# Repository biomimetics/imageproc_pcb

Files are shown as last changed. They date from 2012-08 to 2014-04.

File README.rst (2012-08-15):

This work is licensed under the `Creative Commons Attribution 3.0
Unported License <http://creativecommons.org/licenses/by/3.0/>`_.

================================
ImageProc printed circuit boards
================================

Description:
 ImageProc family of printed circuit boards, which use Microchip's dsPIC
 architecture.

Download boards:
 https://github.com/biomimetics/imageproc_pcb

Citing the boards:
 If you would like to reference these boards in a publication, please
 refer to the url and cite these conference papers:

 - *For ImageProc v.1.x:*

   | Fernando L. Garcia Bermudez and Ronald S. Fearing (2009)
   | `Optical Flow on a Flapping Wing Robot
     <http://dx.doi.org/10.1109/IROS.2009.5354337>`_
   | In IROS 2009. St. Louis, MO, USA.

 - *For ImageProc v.2.0-v2.4-x:*

   | Stanley S. Baek, Fernando L. Garcia Bermudez, and Ronald S. Fearing (2011)
   | `Flight Control for Target Seeking by 13 gram Ornithopter
     <http://dx.doi.org/10.1109/IROS.2011.6094581>`_
   | In IROS 2011. San Francisco, CA, USA.

 - *For ImageProc v2.5-x:*

   | Ryan C. Julian, Douglas D. Hutchings, and Ronald S. Fearing (2012)
   | This design is pending publication.

 This material is based upon work supported by the National Science
 Foundation under Grant No. IIS-0705429 and IIS-0931463. Any opinions,
 findings, and conclusions or recommendations expressed in this material
 are those of the author(s) and do not necessarily reflect the views of
 the National Science Foundation.

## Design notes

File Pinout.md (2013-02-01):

| Pin number | dsPIC ports | ImageProc port(s) | Net name | Function description |
| --- | --- | --- | --- | --- |
| 1 | PWM3H/RE5 | PWM3H/RE5 | MOTOR_C_IN1 | Motor C H-bridge input 1 |
| 2 | PWM4L/RE6 | PWM4L/RE6 | MOTOR_D_IN2 | Motor D H-bridge input 2 |
| 3 | PWM4H/RE7 | PWM4H/RE7 | MOTOR_D_IN1 | Motor D H-bridge input 1 |
| 4 | SCK2/CN8/RG6 | SCK2 | SCK2 | SPI2 for flash and MPU |
| 5 | SDI2/CN9/RG7 | SDI2 | SDI2 | SPI2 for flash and MPU |
| 6 | SDO2/CN10/RG8 | SDO2 | SDO2 | SPI2 for flash and MPU |
| 7 | nMCLR | nMCLR | !RESET | Reset signal (JP1.5) |
| 8 | nSS2/CN11/RG9 | nSS2 | !SS2_1 | SPI2 slave select 1 (flash) |
| 9 | VSS | VSS | GND | Ground |
| 10 | VDD | VDD | 3.3V | Power |
| 11 | AN5/QEB/IC8/CN7/RB5 | - | AN5/QEB/IC8/RB5  | Auxiliary pad 4 |
| 12 | AN4/QEA/IC7/CN6/RB4 | - | AN4/QEA/IC7/RB4  | Auxiliary pad 3 |
| 13 | AN3/INDX/CN5/RB3 | - | AN3/INDX/RB3 | Auxiliary pad 2 |
| 14 | AN2/nSS1/CN4/RB2 | nSS1 | nSS1 | SPI1 for radio |
| 15 | PGEC3/AN1/VREF-/CN3/RB1 | - | AN1/RB1 | Auxiliary pad 1 |
| 16 | PGED3/AN0/VREF+/CN2/RB0 | AN0 | BATT_LEVEL | Battery level sense |
| 17 | PGEC1/AN6/OCFA/RB6 | PGEC1 | PGC | In-circuit debugger (JP1.1) |
| 18 | PGED1/AN7/RB7 | PGED1 | PGD | In-circuit debugger (JP1.2) |
| 19 | AVDD | AVDD | 3.3V | Analog power |
| 20 | AVSS | AVSS | GND | Analog ground |
| 21 | nU2CTS/AN8/RB8 | AN8 | MOTOR_A_BEMF | Motor A BEMF sense |
| 22 | AN9/RB9 | AN9 | MOTOR_B_BEMF | Motor B BEMF sense |
| 23 | TMS/AN10/RB10 | AN10 | MOTOR_C_BEMF | Motor C BEMF sense |
| 24 | TDO/AN11/RB11 | AN11 | MOTOR_D_BEMF | Motor D BEMF sense |
| 25 | VSS | VSS | GND | Ground |
| 26 | VDD | VDD | 3.3V | Power |
| 27 | TCK/AN1/RB12 | RB12 | RD_LED | Red LED |
| 28 | TDO/AN13/RB13 | RB13 | GN_LED | Green LED |
| 29 | nU2RTS/AN14/RB14 | RB14 | YW_LED | Yellow LED |
| 30 | AN15/OCFB/CN12/RB15 | RB15 | RADIO_SLP_TR | Radio control signal |
| 31 | U2RX/SDA2/CN17/RF4 | U2RX | U2RX | Auxiliary UART Rx (JP2.6) |
| 32 | U2TX/SCL2/CN18/RF5 | U2TX | U2TX | Auxiliary UART Tx (JP2.4) |
| 33 | U1TX/SDO1/RF3 | SDO1 | SDO1 | SPI1 for radio |
| 34 | U1RX/SDI1/RF2 | SDI1 | SDI1 | SPI1 for radio |
| 35 | nU2RTS/SCK1/INT0/RF6 | SCK1 | SCK1 | SPI1 for radio |
| 36 | SDA1/RG3 | SDA1 | SDA1 | I2C1 for camera and encoders  |
| 37 | SCL1/RG2 | SCL1 | SCL1 | I2C1 for camera and encoders  |
| 38 | VDD | VDD | 3.3V | Power |
| 39 | OSC1/CLKIN/RC12 | OSC1 | 40MHZ | 40 MHz main oscillator |
| 40 | OSC2/CLKO/RC15 | RC15 | !SS2_2 | SPI2 slave select 2 (MPU) |
| 41 | VSS | VSS | GND | Ground |
| 42 | IC1/nFLTA/INT1/RD8 | INT1 | IMU_IRQ | MPU interrupt |
| 43 | IC2/nU1CTS/nFLTB/INT2/RD9 | INT2 | LOWBATT_IRQ | Low voltage detect interrupt  |
| 44 | IC3/INT3/RD10 | - | IC3/INT3/RD10 | Auxiliary pad 5 |
| 45 | IC4/INT4/RD11 | INT4 | RADIO_IRQ | Radio IRQ interrupt |
| 46 | OC1/RD0 | RD0 | CAM_D0 | Parallel camera bit 0 |
| 47 | PGED2/SOSCI/T4CK/CN1/RC13 | RC13 | CAM_VSYNC | Parallel camera vertical sync |
| 48 | PGEC2/SOSCO/T1CK/CN0/RC14 | RC14 | CAM_PWDM | Parallel camera power down |
| 49 | OC2/RD1 | RD1 | CAM_D1 | Parallel camera bit 1 |
| 50 | OC3/RD2 | RD2 | CAM_D2 | Parallel camera bit 2 |
| 51 | OC4/RD3 | RD3 | CAM_D3 | Parallel camera bit 3 |
| 52 | OC5/IC5/CN13/RD4 | RD4 | CAM_D4 | Parallel camera bit 4 |
| 53 | OC6/IC6/CN14/RD5 | RD5 | CAM_D5 | Parallel camera bit 5 |
| 54 | OC7/CN15/RD6 | RD6 | CAM_D6 | Parallel camera bit 6 |
| 55 | OC8/UPDN/CN16/RD7 | RD7 | CAM_D7 | Parallel camera bit 7 |
| 56 | VCAP | VCAP | N$28 | Charge pump capacitor | 
| 57 | VDD | VDD | 3.3V | Power |
| 58 | C1RX/RF0 | RF0 | CAM_HREF | Parallel camera horiz sync |
| 59 | C1TX/RF1 | RF1 | CAM_PCLK | Parallel camera pixel clock |
| 60 | PWM1L/RE0 | PWM1L/RE0 | MOTOR_A_IN2 | Motor A H-bridge input 2 |
| 61 | PWM1H/RE1 | PWM1H/RE1 | MOTOR_A_IN1 | Motor A H-bridge input 1 |
| 62 | PWM2L/RE2 | PWM2L/RE2 | MOTOR_B_IN2 | Motor B H-bridge input 2 |
| 63 | PWM2H/RE3 | PWM2H/RE3 | MOTOR_B_IN1 | Motor B H-bridge input 1 |
| 64 | PWM3L/RE4 | PWM3L/RE4 | MOTOR_C_IN2 | Motor C H-bridge input 2 |

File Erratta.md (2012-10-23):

ImageProc 2.5 Errata

=Revision C=

=Revision B=
* SCL1 and SDA1 are transposed on the dsPIC33 footprint

=Revision A=

*V_batt plane connecting to the vregs.

Symptom:
The voltage regulators do not draw power from the battery

Reason:
The V_batt source does not connect to the portion of the V_batt plane that the voltage regulators draw power from. This occurs because the V_batt plane was cut off due to the vias that power IC7. This connection is made in Eagle, but the gerbers that the manufactuer uses exlucded the connection.

Short term resolution: Airwire between one of the three isolated vias (one each for the two vregs, one for the top H-bridge chip), and a portion of v_batt that is connected (typically, the other v_batt via for IC7).

Long Term Resoultion: Re-route those two wires that are cutting the majority of the plane off.

* Programming Connector pinouts

Symptom: The dsPIC cannot be programmed with legacy programming adaptors

Reason: The programming connector does not have the same pinouts as the programming connector on ImageProc 2.4

Short Term Resolution: Plug in the prog connector with the cable, and ensure that the cable is upside down on the connector. Then, before the final connector interfaces with the pic kit, use male-female wires to rearrange the pins to the correct orientation.

Long Term Resolution: re-do the connector on the schematic and board files.

* IC7 ground pin

Symptom: IC7, one of the two motor controllers, does not work.

Reason: One of its three ground pins, specifically, pin 11, is soldered to a pad that is in fact not connected with ground.

Short Term Resolution: Airwire between than pad and a source of ground.

Long Term Resoultion: A new route that connects ground.

* C40 and C37 mix-up

Symptom: C40, the bypass capacator for the flash mem, and C37, the bypass capacator for the IMU, have been mislabled as eachother.

Short Term resolution: Populate both C37 and C40.  Both C37 and C40 have the same value.

Long Term: Re-lable the eagle file.

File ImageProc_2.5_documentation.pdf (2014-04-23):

U_BATT

| | | | 3.3U | | 2.5U
U_BATT | U_BATT ~ | ~
~ | ~ | IC2 | IC3
U_BATT | a | ~ | 1 | ::C1 | 1 | ::C2
IC1 | VIN | VIN BATT _LEUEL
_g__ | IiuF | _g__ | IiuF C3 | ,___]__ | UIN | _____2____ L 0 W B A TT _IRQ | iuF | ,___'[ | EN_3.3l) 3.3l) | iuF | ,___'[ | EN_2.5l) 2.5l)
0.1uF: = 1 | lJOUT | C6 | c,= = | C5: = uss | ~
= =0.1uF
___2 | EN_3.0l) | 3.0 | )j_ | GND | ___2 | EN_1.8l) 1.8l) | )j_ | GND ~ N | N XC61GC3002HR-G | a | 2•2 | 2•2
GND | GND | 3.0U | GND | 1.8U
do | GND
MIC5335 SPYMT
GND

MIC5335 JGYMT

~ | ~
::C7 | ::CB
JuF | JuF
GND | GND

Biomimetic Millisldstems Labor atorld
Department of EECS., Universitld of California., Berkeleld CopldriCJht 2012 UC ReCJents" All riCJhts reserved"
TITLE: ImagePmc_2.5
Design by: | REV:
Ryan Julian (ryan julian@ berkeley. e d u) | A
Date: 7/26/12 11:03 AM | Sheet: 1/5

ICiRESET/CLOCK/DEBUG
u | RESET /CLOCK/DEBUG
il_~'v·~?~k--~DCSCT~~~~PM~CCLP~~~~~c=~~~P~G~ED~1~/~A~N~7/~R;B;7~~ PGD
R3 | i0MH2____]_.9_ OSC1/CLKIN/RC12 | PGEC1/AN6/0CFA/R86 | 1Z__ PGC
LOWBATT _IRQ | ____g RADIO_IRQ | _12
AN1/RB1 | | ~
AN3/INDX/RB3 | | ~
ANi/QEA/IC7/RBi ~
AN5/QEB/IC8/RB5 ~
RD_LED | | ~
GN_LED | | ~
YW LED | | ~
RADID_SLP_TR | | ~

DSPIC33FJ128MC706A

ICiGPIO
GPID
IC2/U1CTS/FLTB/INT2/PD8 | OC1/RDO
IC1/INT1/PDii | OC2/RD1
OC3/RD2
PGEC3/AN1/UPEF-/CN3/P81 | OC1/PD3
AN3/INDX/CN5/P83 | DC5/IC5/CN13/PD1
AN1/QEA/IC7/CN6/P81 | DC6/IC6/CN11/PD5
AN5/QE8/IC8/CN7/P85 | OC7/CN15/PD6
TCK/AN12/P812 | OC8/UPDN/CN16/PD7
TDI/AN13/R813 | 1Ci/FLTA/INT1/PD8
U2PTS/AN1 1/P811 | IC3/INT3/PD10
AN15/0CFB/CN12/P815

~ CAM_D0
~ CAM_Di
~ CAM_D2
~ CAM_D3
~ CAM_Di
~ CAM_D5
~ CAM_D6
~ CAM 07 ~ IMU -IRQ
ii_ IC3/INT3/R010

CAM_USYNC
CAM_PWDN | ~ | PGED2/SOSCI/T1CK/CN1/PC13
| ~ | PGEC2/SOSCO/T1CK/CNO/PC11
C1RX/PFO | ~ CAM_HREF
C1 TX/PFi | ~ CAM_PCLK
| | DSPIC33FJ128MC706A

3.3U
OSCi
4 UDD OUT ]_______ i0MHZ
C9 :: | _.1_ EN | GND 2

I 0·iuF ECS 2033 100

GND | GND
IC"'-P _AUDD | IC"'-P _U00@10 IC"'-P _U00@26 IC"'-P _U00@38 IC"'-P _U00@57 IC"'-P _UCAP I
r( 3.3U | 3.3U | 3.3U

# ~~11 ~f112 ~f113 3.3U

# ~hCH 1C15

:t!0.1uF | r0.1uF | :t!0.1uF | J!0.1uF | I0.1uF | Ii.7uF
| | | | GND | GND
GND | GND | GND | GND

IC"'-SERIAL
SERIAL
SCKi ~ U1PTS/SCK1/INTO/PF6 | SCK2/CN8/PG6 SOil~ U1PX/SDI1/PF2 | SDI2/CN8/PG7
SDOi ~ U1TX/SDD1/PF3 | SD02/CN10/PG8
3.3U | SSi ___l_i AN2/SS1/CN1/P82 | SS2/CN11/PG8
OSC2/CLKO/PC15
i.7k | SCI 1 | 36 | SCL1/PG2 | U2TX/SCL2/CN18/PF5
R' | | 37 | SDA1/PG3 | U2PX/SDA2/CN17/PF1
i.7k J | DSPIC33FJ128MC706A

R5

IC"'-PWM
PWM

MOTOR_A_INi ~ PWM1H/PE1
MOTOR_A_IN2 ____g_Q_ PWM1L/PEO

PWM3H/PE5
PWM3L/PE1

~ SCK2
~ SDI2
~ SD02
~ SS2 1
.iQ_ SS2=2

~ U2TX
].1_ U2RX
MOTOR_B_INi ----@- PWM2H/PE3 | PWM1H/RE7 ~ MOTOR_D_INi
MOTOR_B_IN2 _____gl_ PWM2L/PE2 | PWM1L/RE6 L_ MOTOR_D_IN2
~DS~P~I~C~3~3~F~J~12~8~M=c~7~0~6~A--------------_j

IC"'-ANALOG
ANALOG

BATT _LEUEL ___lQ PGED3/ANO/UPEF+/CN2/RBO

MOTOR_A_BEM~ ~ U2CTS/AN8/PBB MOTOR_B_BEM~ ~ AN9/PB9
MOTOR_C_BEM~ ~ TMS/AN10/P810 MOTOR_D_BEMF ____21_ TDO/ANii/PB11
| DSPIC33FJ128MC706A

Biomimetic Millisldstems Labor atorld
Department of EECS., Universitld of California., Berkeleld CopldriCJht 2012 UC ReCJents" All riCJhts reserved"
TITLE: ImagePmc_2.5
Design by:
Ryan Julian (ryan julian@ berkeley. e d u)

REV:
A
Date: 7/26/12 11:03 AM | I Sheet: 2/5

3.3U
IC5P_AUDD ~_EUDD
0.1uci ~1 121

# C20T ~~ TiuF ~_AVSS GND

IC5S
RESET | __fL_ | PST | RFP
RFN SCK1 | --+!-- | SCLK SDI1 | ~ | MISO | DIGi 5001 | ~ | MOSI | DIG2 SS1 | __2]_ | SEL
RADIO IRQ | ~ | DIG3
IRQ | DIG4- RADIO=SLP_TR ~ | SLP TP -
26 | XTALi __2L | XTAL2 | CLKM
OSC2 | AT86RF233 ZU
C18 ._:l---jOf---2- C19
10pF:~ | ;;__=::10pF

NX2520SA- 6.000000MHZ
GND | GND

3.31J
IC5P _DUDD ~ _DEIJDD
0.1ucl ~~ 123

# C22T ~~ TiuF ~_DVSS GND

4
5
+o

+- _2_

_:1Z

81
HHM171001

C16
22pF::
L;'"-

GND (") '"""
C17
22pF::

RED
LED_TX R6
.... 2.7k
GREEN
LED_RX R7
.... 2.7k

Jo
Jo

ANTi
ANT8030-2R1--01A

Biomimetic Millisldstems Labor atorld
Department of EECS., Universi1ld of California., BerkeleLJ CopLJriCJht 2012 UC ReCJents" All riCJhts reserved"
TITLE: ImagePmc_2.5
Design by: | REV:
Ryan Julian (ryanjulian@berkeley.edu) A
Date: 7/26/12 11:03 AM | I Sheet: 3/5

RB
IC7S | R9 | 15k ,7, MOTOR_A_IN1 | AIN1 | AOUTi | MOTOR_A_OUTi | MOTOR A OUTi | R29 MOTOR A IN2 | AIN2 | AOUT2 | MOTOR A OUT2 | 1 | MOTOR A BEMF
MOTOR A OUT2 | 1k | CH
R10 | LTC6088 | I2.2nF MOTOR_B_IN1 | BIN1 | BOUTi | MOTOR_B_OUTi | ,7, | IC6A
MOTOR B IN2 | BIN2 | BOUT2 | MOTOR B OUT2 | ~ | ~
~ | CD
15 | a | ~ | GND SLEEP FAULT
u BATT | u REF

A IS EN
BISEN | R12
DRU8833RTY | R13 | 15k GND | ,7, MOTOR B OUTi | R30 | MOTOR B BEMF
MOTOR B OUT2 | 1k | C'2 | 3.3U R14 | LTC6088 | I2.2nF ,7, | IC6B
CD | | ~
~ | CD a | ~ | GND | ~
u REF | "' ~ | ~
a | "' U_REF

R17
C26
R19 | 15k | ~
ICBS | ~ ,7, | "' MOTOR_C_IN1 | AIN1 | AOUTi | MOTOR_C_OUTi | MOTOR C OUTi | R31 MOTOR C IN2 | AIN2 | AOUT2 | MOTOR C OUT2 | 10 | MOTOR C BEMF
MOTOR C OUT2 | 1k | C'3
R20 | LTC6088 | I2.2nF MOTOR_D_IN1 | BIN1 | BOUTi | MOTOR_D_OUTi | ,7, | IC6C | GND
MOTOR D IN2 | BIN2 | BOUT2 | MOTOR D OUT2 | ~ | ~
N | CD
15 | a | ~ | GND SLEEP FAULT
u BATT | u REF

A IS EN
BISEN | R22
DRIJ8833RTY | R23 | 15k GND | ,7, MOTOR D OUTi | R32 16 | MOTOR D BEMF
MOTOR D OUT2 | 1k | CH
R24 | LTC6088 | I2.2nF ,7, | IC6D
CD | ~
N | CD a | ~ | GND
u REF
IC7P _IJM | IC7P _IJCP IC7P _IJINT | ICBP _IJM | ICBP _IJCP ICBP _IJINT | 3.31J
U_BATT | U_BATT | U_BATT | U_BATT | Biomimetic Millisldstems Labor atorld
~f130131 132 | ~f133131 135
IC6Ph | Department of EECS., Universitld of California., Berkeleld
T | C29 | CopldriCJht 2012 UC ReCJents" All riCJhts reserved"

p0.1uF

TITLE: ImagePmc_2.5

p22uFJ"0nF | T2uF | p22uFJ"0nF | T2uF | Design by: | REV:
Ryan Julian (ryan julian@ berkeley. e d u) | A GND
GND | GND | GND | GND | Date: 7/26/12 11:03 AM | Sheet: 4/5

U_BATT
Pi BAT+~ P2 BAT-*l

GND

YELLOW
YW_LEO | LED1
| GREEN ""
GN_LEO | LED2
RED ""

RO_LEO LED3
""
P3 | MA1 x-- MOTOR_A_OUTi
p' | MA2 x-- MOTOR A OUT2 - | -
P5 | MB1 x-- MOTOR_B_OUTi
P6 | MB2 x-- MOTOR B OUT2 - | -
P7 | MC1 x-- MOTOR_C_OUTi
PB | MC2 x-- MOTOR C OUT2 - | -
P9 | MD1 x-- MOTOR_D_OUTi
P10 MD2 x-- MOTOR D OUT2 - | -

R26

2.7k
R27

2.7k
R2B

2.7k
GND

IC9S
5CK2
5DI2 | __q_ SCL/SCLK AUX_CL + ~ ADO/SOD AUX_DA --"--
5002 | 8 | SDA/SDI
552 2 - | | cs
CAM_HREF _____11_ FSYNC | INT ______12_ IMU_IRQ

IC9P _IJOO
3.31J
~f137

~ CLKIN CLKOUT ______2_2_
A"MP"'U-,---6⁰⁰0"0"0,-----_j GND

IC9P _CPOUT IC9P _REGOUT

| 1.2nF | 1.1uF
1!0.1uF | T38 | T39
GND | GND | GND

IC10P
3.31J
~f1,0 r0.1uF

GND

3.3U

P£bfX_503 80-0600
-+--- 3
- 4--- -Jj_
-"'--

## TPT """' GND

3.3U 1-- IC105

l__g_ uP

RESET
3.3U
GND
PGD
PGC

RESET _______]_____ RESET
5CK2 | ----+-- SCK
5DI2 | ~ so
5002 | ~ Sl
5 s 2 _1 ______i_ cs
| AT1-5DB6"'1-20-CNU

U_BATT

P£bfX
1

_503 80-0600
U_BATT
2 | U_BATT
3 | GNO
-4--- 5 | U2TX -f"----< GND
-li__ | U2RX

## TP2 """' GND

3.3U

P£hf~_503 80-0600
3.3U
GND
SCLi
GND
SOAi
GND

3.3U
3.3U~ Pii )E-- AN1/RB1 2
-+---
-~

LBU t5U l

I | GND
2.5U | Jo

P12 )E-- AN3/INOX/RB3
P13 )E-- AN1-/QEA/IC7/RB"''-P11- )E-- AN5/QEB/ICB/RB5
P16 )E-- IC3/INT3/R010

GNO *l

GND

JP'

CAM_D6 | | ~
"''-0MHZ | ~ CAM 07 | ___l]_
? 'il~ | | 11
| | 15
CAM_HREF ~
CAM PWON, ~
CAM=IJSYNC ~
| | 19
SCL1 | | ~
2.5U | | 21

NC
NC
02
01
03
DO

GND

SOA11 ~

~

~----------~ | 2~

01
PCLK
05
DGND
06
XCLK
07
DOIJDD
DIJDD
HREF
PWDN
IJSYNC
RESET
SIO_C
AIJDD
SIO_D
AGND
NC
0.1uF
::C36

Biomimetic Millisldstems Labor atorld
Department of EECS., Universitld of California., Berkeleld CopldriCJht 2012 UC ReCJents" All riCJhts reserved"
TITLE: ImageProc_2.5
Design by: | REV:
Ryan Julian (ryanjulian@berkeley.edu) A
Date: 7/26/12 11:03 AM | Sheet: 5/5

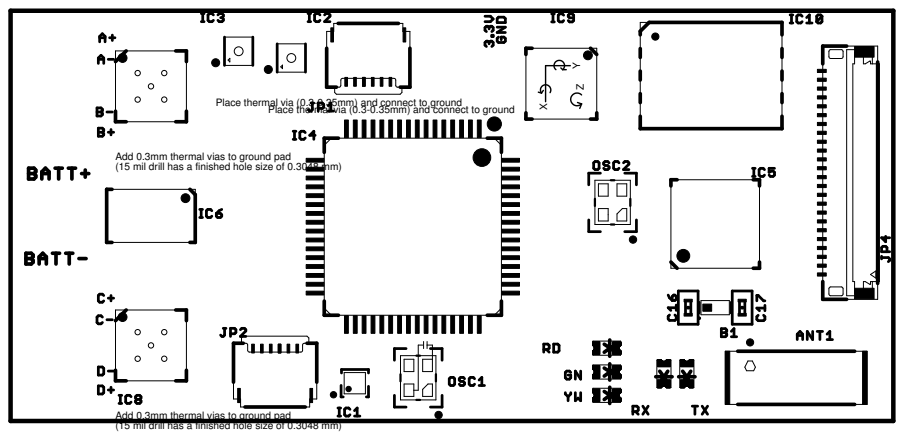
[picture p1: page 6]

Place thermal via (0.3-0.35mm) and connect to ground

Add 0.3mm thermal vias to ground pad
(15 mil drill has a finished hole size of 0.3048 mm)

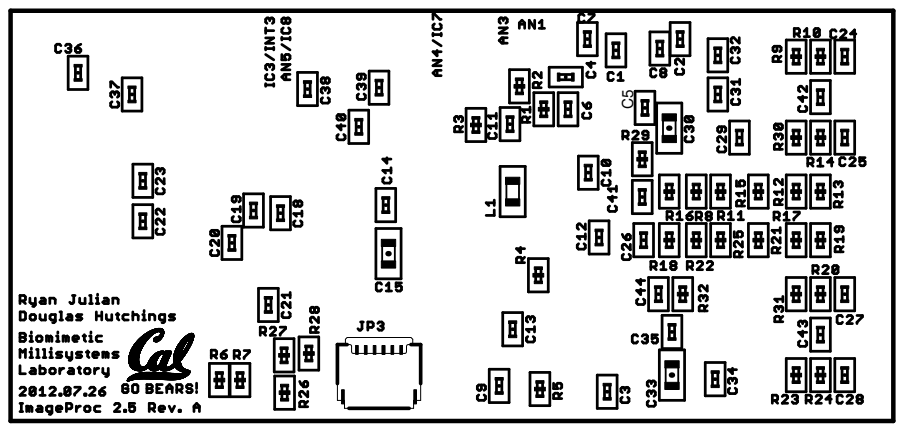
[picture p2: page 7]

Qty Value | Parts | Device | Vol | Description
1 | ANT8030-2R4-01A | ANT1 | ANT8030-2R4-01A
1 | AT45DB642D-CNU | IC10 | AT45DB642D-CNU
1 | AT86RF233-ZU | IC5 | AT86RF233-ZU
20 | 0.1uF | CAP0402-CAP | 10% 16V X7R | Capacitor
2 | 10nF | C31, C34 | CAP0402-CAP | | 16V X7R | Capacitor
2 | 10pF | C18, C19 | CAP0402-CAP | 10% 50V C0G | Capacitor
8 | 1uF | CAP0402-CAP | 10% 16V X5R | Capacitor
5 | 2.2nF | C38, C41, C42, C43, C44 CAP0402-CAP | 10% 50V X7R | Capacitor
2 | 2.2uF | C32, C35 | CAP0402-CAP | 10% 6.3V | Capacitor
2 | 22pF | C16, C17 | CAP0402-CAP | 5% | 50V C0G | Capacitor
2 | 22uF | C30, C33 | CAP0603-CAP | | | Capacitor
1 | 4.7uF | C15 | CAP0603-CAP | | 16V | Capacitor
2 | DRV8833RTY | IC7, IC8 | DRV8833RTY
1 | DSPIC33FJ128MC706A | IC4 | DSPIC33FJ128MC706A
1 | ECS-2033-400 | OSC1 | ECS-2033-400 | | | ECS 3.3V 40MHz oscillator
1 | HHM1710D1 | B1 | HHM1710D1
1 | 4.7uH | L1 | INDUCTOR0603 | | | Inductors
2 | GREEN | LED2, LED_RX | LED0603 | | | LEDs
2 | RED | LED3, LED_TX | LED0603 | | | LEDs
1 | YELLOW | LED1 | LED0603 | | | LEDs
1 | LTC6088 | IC6 | LTC6088
1 | MIC5335-JGYMT | IC3 | MIC5335-JGYMT
1 | MIC5335-SPYMT | IC2 | MIC5335-SPYMT
3 | MOLEX_503480-0600 | JP1, JP2, JP3 | MOLEX_503480-0600
1 | MPU-6000 | IC9 | MPU-6000
1 | NX2520SA-16.000000MHZ OSC2 | NX2520SA-16.000000MHZ | 644-1059-6-ND
1 | 51441-2493-C | JP4 | OV7660FSL_CON
Tol | Dielec

C3, C6, C9, C10, C11, C12, C13, C14, C20, C22, C24,
C25, C26, C27, C28, C29,
C36, C37, C39, C40

C1, C2, C4, C5, C7, C8,
C21, C23

TI DRV8833 1.5A Dual H-Bridge Motor Driver IC

14MHz, Rail-to-Rail Output, 12nV/Hz, 1.1mA Op Amp
Micrel MIC5335 150mA dual
(2.5V/1.8V) voltage regulator Micrel MIC5335 150mA dual
(3.3V/3.0V) voltage regulator.

MPU-6000 3-axis gyro + 3-axis accelerometer, SPI/I2C
interface with auxiliary I2C interface for magnetometer

8 | 15k | | RESISTOR0402-RES | | Resistor
5 | 1k | R1, R29, R30, R31, R32 | RESISTOR0402-RES | 1% | Resistor
6 | 2.7k | R2, R6, R7, R26, R27, R28 RESISTOR0402-RES | 1% | Resistor
5 | 4.7k | R3, R4, R5, R16, R18 | RESISTOR0402-RES | 1% | Resistor
8 | 47k | | RESISTOR0402-RES | 1% | Resistor
1 | XC61GC3002HR-G | IC1 | XC61GC3002HR-G
| | R8, R11, R12, R15, R17, R21, R22, R25

R9, R10, R13, R14, R19,
R20, R23, R24
Torex XC61GC3002HR-G 3.0V
voltage detector.

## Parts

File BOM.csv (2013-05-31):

Qty to build: | 20
Revision: | 1
Quantity | Designator | Description | Value | Manufacturer | Part Number | Distributor | Distributor Part # | Incl. In Kit | Need for Build | Qty. To Return | Comments | Unit Price | Build price
20 | C3, C6, C9, C10, C11, C12, C13, C14, C20, C22, C24, C25, C26, C27, C28, C29, C36, C37, C39, C40 | CAP CER 0.1UF 16V 10% X7R 0402 | 0.1uF | Murata | GRM155R71C104KA88D | Digi-Key | 490-3261-1-ND | N/A | 400 | N/A |  | $0.00632 | $0.13
2 | C31, C34 | CAP CER 10000PF 25V 10% X8R 0402 | 10nF | TDK | C1005X8R1E103K050BA | Digi-Key | 445-2494-1-ND | N/A | 40 | N/A |  | $0.12400 | $2.48
2 | C18, C19 | CAP CER 10PF 50V 5% NPO 0402 | 10pF | Yageo | CC0402JRNPO9BN100 | Digi-Key | 311-1014-2-ND | N/A | 40 | N/A |  | $0.00920 | $0.18
8 | R8, R11, R12, R15, R17, R21, R22, R25 | RES 15K OHM 1/10W 1% 0402 SMD | 15k | Panasonic | ERJ-2RKF1502X | Digi-Key | P15.0KLCT-ND | N/A | 160 | N/A |  | $0.01840 | $0.37
5 | R1, R29, R30, R31, R32 | RES 1K OHM 1/10W 5% 0402 SMD | 1k | Panasonic | ERJ-2GEJ102X | Digi-Key | P1.0KJCT-ND | N/A | 100 | N/A |  | $0.01310 | $0.26
8 | C1, C2, C4, C5, C7, C8, C21, C23 | CAP CER 1UF 16V 10% X5R 040 | 1uF | TDK | C1005X5R1C105K050BC | Digi-Key | 445-4978-1-ND | N/A | 160 | N/A |  | $0.03800 | $0.76
5 | C38, C41, C42, C43, C44 | CAP CER 2200PF 50V 10% X7R 0402 | 2.2nF | Taiyo Yuden | UMK105B7222KV-F | Digi-Key | 587-1221-1-ND | N/A | 100 | N/A |  | $0.00660 | $0.13
2 | C32, C35 | CAP CER 2.2UF 10V 20% X5R 0402 | 2.2uF | Taiyo Yuden | LMK105BJ225MV-F | Digi-Key | 587-3153-1-ND | N/A | 40 | N/A |  | $0.12800 | $2.56
6 | R2, R6, R7, R26, R27, R28 | RES 2.7K OHM 1/10W 5% 0402 SMD | 2.7k | Panasonic | ERJ-2GEJ272X | Digi-Key | P2.7KJCT-ND | N/A | 120 | N/A |  | $0.00131 | $0.03
2 | C16, C17 | CAP CER 22PF 50V 5% NP0 0402 | 22pF | Murata | GRM1555C1H220JZ01D | Digi-Key | 490-1283-1-ND | N/A | 40 | N/A |  | $0.02800 | $0.56
2 | C30, C33 | CAP CER 22UF 6.3V 20% X5R 0603 | 22uF | TDK | C1608X5R0J226M080AC | Digi-Key | 445-8028-1-ND | N/A | 40 | N/A |  | $0.33600 | $6.72
5 | R3, R4, R5, R16, R18 | RES 4.7K OHM 1/10W 1% 0402 SMD | 4.7k | Panasonic | ERJ-2RKF4701X | Digi-Key | P4.70KLCT-ND | N/A | 100 | N/A |  | $0.01840 | $0.37
1 | C15 | CAP CER 4.7UF 16V 10% X5R 0603 | 4.7uF | Taiyo Yuden | EMK107ABJ475KA-T | Digi-Key | 587-2786-1-ND | N/A | 20 | N/A |  | $0.21600 | $4.32
1 | L1 | INDUCTOR MULTILAYER 4.7UH 0603 | 4.7uH | TDK | MLF1608A4R7K | Digi-Key | 445-1021-1-ND | N/A | 20 | N/A |  | $0.17000 | $3.40
8 | R9, R10, R13, R14, R19, R20, R23, R24 | RES 47K OHM 1/10W 1% 0402 SMD | 47k | Panasonic | ERJ-2RKF4702X | Digi-Key | P47.0KLCT-ND | N/A | 160 | N/A |  | $0.01840 | $0.37
1 | JP4 | 24-position SMD ZIF FPC connector |  | Molex | 51441-2493-C | Digi-Key | Do not populate | N/A | 20 | N/A | Not to be populated during assembly |  | $-
1 | ANT1 | Chip Mulitlayer Antenna for 2.4 GHz W-LAN / Bluetooth |  | TDK | ANT8030-2R4-01A | Digi-Key | 445-3719-1-ND | N/A | 20 | N/A |  | $4.56700 | $91.34
1 | IC10 | 64-megabit 2.7V Dual-interface DataFlash |  | Atmel | AT45DB642D-CNU | Digi-Key | AT45DB642D-CNU-ND | N/A | 20 | N/A |  | $5.81000 | $116.20
1 | IC5 | Low Power, 2.4GHz Transceiver for ZigBee, RF4CE, IEEE 802.15.4, 6LoWPAN, and ISM Applications |  | Atmel | AT86RF233-ZU | Digi-Key | AT86RF233-ZU-ND | N/A | 20 | N/A |  | $4.73000 | $94.60
2 | IC7, IC8 | Dual H-Bridge Motor Driver |  | TI | DRV8833RTY | Digi-Key | 296-29513-1-ND | N/A | 40 | N/A |  | $2.55440 | $51.09
1 | IC4 | 16-bit Digital Signal Controllers (up to 256 KB Flash and 30 KB SRAM) with Motor Control and Advanced Analog |  | Microchip | DSPIC33FJ128MC706A-I/PT | Digi-Key | DSPIC33FJ128MC706A-H/PT-ND | N/A | 20 | N/A |  | $8.17000 | $163.40
1 | OSC1 | 3.3V 40MHz subminiature SMD oscillator |  | ECS | ECS-2033-400 | Digi-Key | XC1437CT-ND | N/A | 20 | N/A |  | $2.87300 | $57.46
2 | LED2, LED_RX | LED GREEN CLEAR 0603 SMD |  | Lite-On | LTST-C190KGKT | Digi-Key | 160-1435-1-ND | N/A | 40 | N/A |  | $0.22800 | $4.56
1 | B1 | Multilayer Balun Transformers for 2.4GHz W-LAN/Bluetooth |  | TDK | HHM1710D1 | Digi-Key | 445-3246-1-ND | N/A | 20 | N/A |  | $2.18300 | $43.66
1 | IC6 | 14MHz, Rail-to-Rail Output, 12nV/Hz, 1.1mA Op Amp |  | Linear | LTC6088CDHC | Digi-Key | LTC6088HDHC#PBF-ND | N/A | 20 | N/A |  | $3.42000 | $68.40
1 | IC3 | 150mA dual (2.5V/1.8V) voltage regulator |  | Micrel | MIC5335-JGYMT | Digi-Key | 576-3589-1-ND | N/A | 20 | N/A |  | $1.98000 | $39.60
1 | IC2 | 150mA dual (3.3V/3.0V) voltage regulator |  | Micrel | MIC5335-SPYMT | Digi-Key | 576-1949-1-ND | N/A | 20 | N/A |  | $1.98000 | $39.60
3 | JP1, JP2, JP3 | CONN .5MM FPC 6POS RA SMD B-FLIP |  | Molex | 503480-0600 | Digi-Key | WM1387DKR-ND | N/A | 60 | N/A |  | $0.64380 | $12.88
1 | IC9 | MPU-6000 3-axis gyro + 3-axis accelerometer, SPI/I2C interface with auxiliary I2C interface for magnetometer |  | InvenSense | MPU-6000 | InvenSense | MPU-6000 | N/A | 20 | N/A |  | $15.00000 | $300.00
1 | OSC2 | CRYSTAL 16.000000MHZ 10PF SMD |  | NDK | NX2520SA-16.000000MHZ | Digi-Key | 644-1059-1-ND | N/A | 20 | N/A |  | $1.83900 | $36.78
2 | LED3, LED_TX | LED SUPER RED CLEAR 0603 SMD |  | Lite-On | LTST-C190KRKT | Digi-Key | 160-1436-1-ND | N/A | 40 | N/A |  | $0.22800 | $4.56
1 | IC1 | 3.0V voltage detector |  | Torex | XC61GC3002HR-G | Digi-Key | 893-1046-1-ND | N/A | 20 | N/A |  | $0.49400 | $9.88
1 | LED1 | LED YELLOW CLEAR 0603 SMD |  | Lite-On | LTST-C190KSKT | Digi-Key | 160-1437-1-ND | N/A | 20 | N/A |  | $0.24800 | $4.96

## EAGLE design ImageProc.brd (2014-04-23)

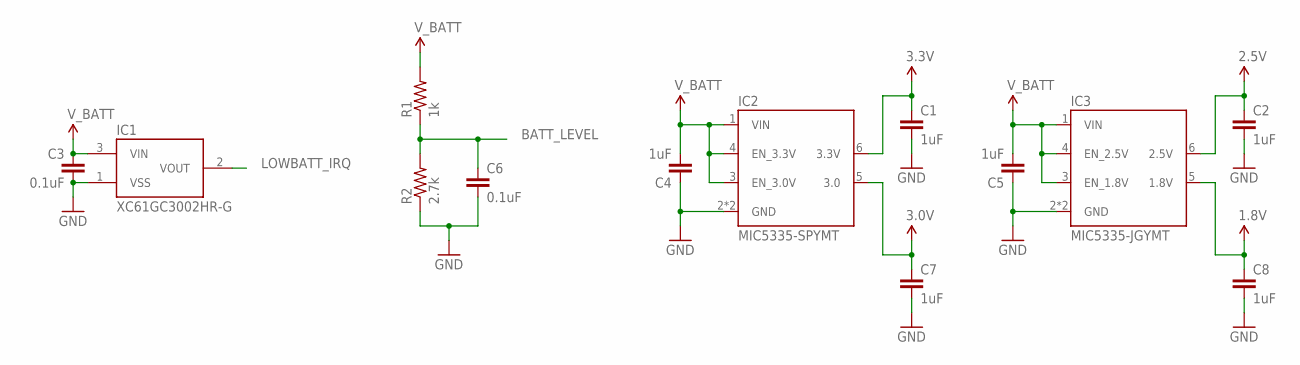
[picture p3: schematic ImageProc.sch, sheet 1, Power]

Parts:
C1, C2, C4, C5, C7, C8: 1uF; 0402-CAP
C3, C6: 0.1uF; 0402-CAP
IC1: XC61GC3002HR-G; USP-3
IC2: MIC5335-SPYMT; MLF-6
IC3: MIC5335-JGYMT; MLF-6
R1: 1k; 0402-RES
R2: 2.7k; 0402-RES

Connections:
1.8V: C8.1, IC3.5 (1.8V); also elsewhere on the board
2.5V: C2.1, IC3.6 (2.5V); also elsewhere on the board
3.0V: C7.1, IC2.5 (3.0)
3.3V: C1.1, IC2.6 (3.3V); also elsewhere on the board
BATT_LEVEL: C6.1, R1.1, R2.2; also elsewhere on the board
GND: C1.2, C2.2, C3.2, C4.1, C5.1, C6.2, C7.2, C8.2, IC1.1 (VSS), IC2.2 (GND), IC2.EPAD (GND), IC3.2 (GND), IC3.EPAD (GND), R2.1; also elsewhere on the board
LOWBATT_IRQ: IC1.2 (VOUT); also elsewhere on the board
V_BATT: C3.1, C4.2, C5.2, IC1.3 (VIN), IC2.1 (VIN), IC2.3 (EN_3.0V), IC2.4 (EN_3.3V), IC3.1 (VIN), IC3.3 (EN_1.8V), IC3.4 (EN_2.5V), R1.2; also elsewhere on the board

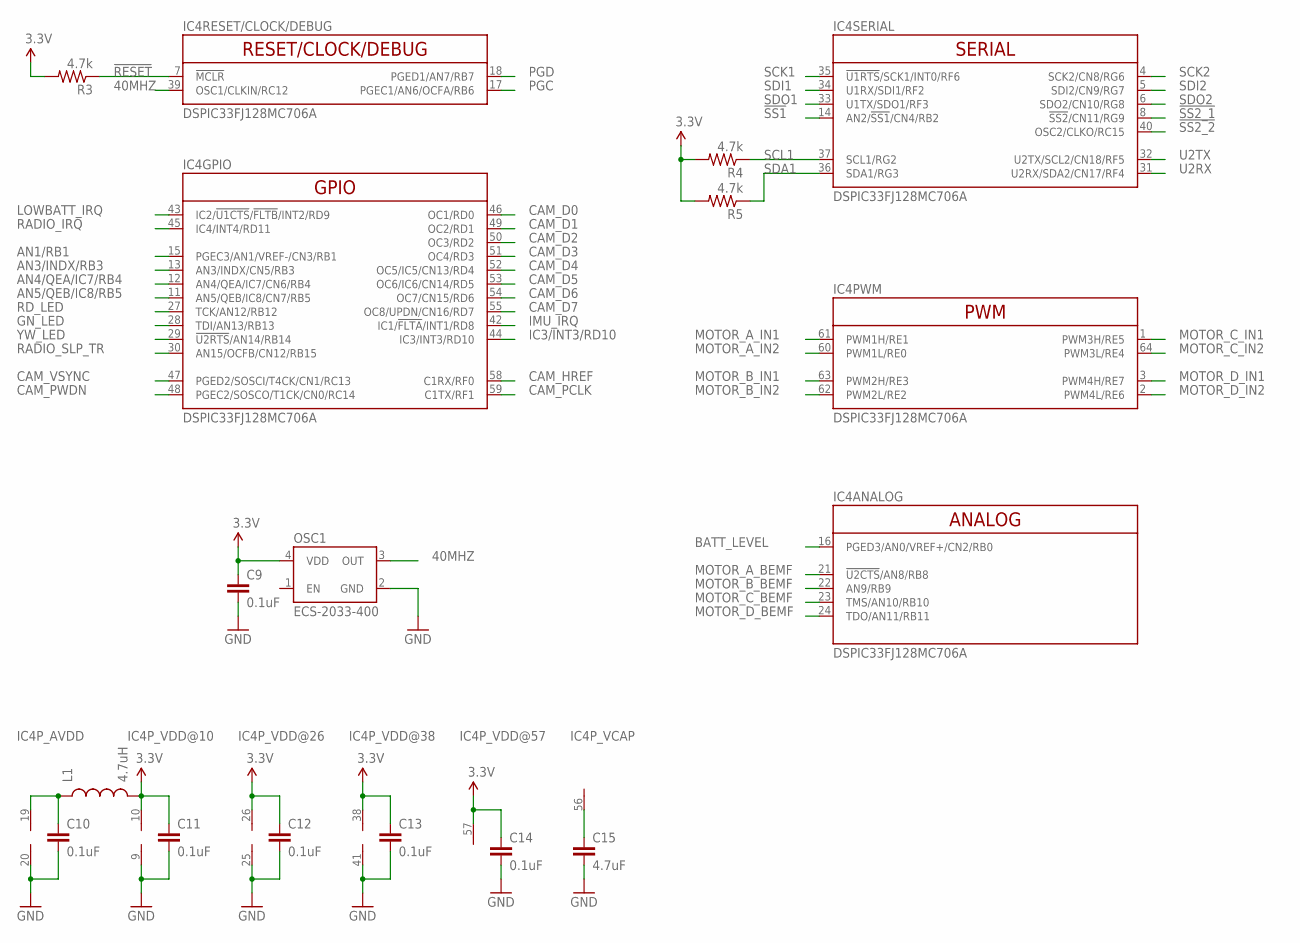
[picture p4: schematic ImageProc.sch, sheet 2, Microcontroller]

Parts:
C9, C10, C11, C12, C13, C14: 0.1uF; 0402-CAP
C15: 4.7uF; 0603-CAP; VOLTAGE 16V
IC4: DSPIC33FJ128MC706A; TQFP-64
L1: 4.7uH; 0603
OSC1: ECS-2033-400; OSCILLATOR-SMD
R3, R4, R5: 4.7k; 0402-RES

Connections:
3.3V: C9.1, C11.1, C12.1, C13.1, C14.1, IC4.10 (V+), IC4.26 (V+), IC4.38 (V+), IC4.57 (V+), L1.2, OSC1.4 (VDD), R3.2, R4.2, R5.2; also elsewhere on the board
40MHZ: IC4.39 (OSC1/CLKIN/RC12), OSC1.3 (OUT); also elsewhere on the board
!RESET: IC4.7 (!MCLR), R3.1; also elsewhere on the board
!SS1: IC4.14 (AN2/!SS1!/CN4/RB2); also elsewhere on the board
!SS2_1: IC4.8 (!SS2!/CN11/RG9); also elsewhere on the board
!SS2_2: IC4.40 (OSC2/CLKO/RC15); also elsewhere on the board
AN1/RB1: IC4.15 (PGEC3/AN1/VREF-/CN3/RB1); also elsewhere on the board
AN3/INDX/RB3: IC4.13 (AN3/INDX/CN5/RB3); also elsewhere on the board
AN4/QEA/IC7/RB4: IC4.12 (AN4/QEA/IC7/CN6/RB4); also elsewhere on the board
AN5/QEB/IC8/RB5: IC4.11 (AN5/QEB/IC8/CN7/RB5); also elsewhere on the board
BATT_LEVEL: IC4.16 (PGED3/AN0/VREF+/CN2/RB0); also elsewhere on the board
CAM_D0: IC4.46 (OC1/RD0); also elsewhere on the board
CAM_D1: IC4.49 (OC2/RD1); also elsewhere on the board
CAM_D2: IC4.50 (OC3/RD2); also elsewhere on the board
CAM_D3: IC4.51 (OC4/RD3); also elsewhere on the board
CAM_D4: IC4.52 (OC5/IC5/CN13/RD4); also elsewhere on the board
CAM_D5: IC4.53 (OC6/IC6/CN14/RD5); also elsewhere on the board
CAM_D6: IC4.54 (OC7/CN15/RD6); also elsewhere on the board
CAM_D7: IC4.55 (OC8/UPDN/CN16/RD7); also elsewhere on the board
CAM_HREF: IC4.58 (C1RX/RF0); also elsewhere on the board
CAM_PCLK: IC4.59 (C1TX/RF1); also elsewhere on the board
CAM_PWDN: IC4.48 (PGEC2/SOSCO/T1CK/CN0/RC14); also elsewhere on the board
CAM_VSYNC: IC4.47 (PGED2/SOSCI/T4CK/CN1/RC13); also elsewhere on the board
GND: C9.2, C10.2, C11.2, C12.2, C13.2, C14.2, C15.2, IC4.9 (V-), IC4.20 (V-), IC4.25 (V-), IC4.41 (V-), OSC1.2 (GND); also elsewhere on the board
GN_LED: IC4.28 (TDI/AN13/RB13); also elsewhere on the board
IC3/INT3/RD10: IC4.44 (IC3/INT3/RD10); also elsewhere on the board
IMU_IRQ: IC4.42 (IC1/!FLTA!/INT1/RD8); also elsewhere on the board
LOWBATT_IRQ: IC4.43 (IC2/!U1CTS!/!FLTB!/INT2/RD9); also elsewhere on the board
MOTOR_A_BEMF: IC4.21 (!U2CTS!/AN8/RB8); also elsewhere on the board
MOTOR_A_IN1: IC4.61 (PWM1H/RE1); also elsewhere on the board
MOTOR_A_IN2: IC4.60 (PWM1L/RE0); also elsewhere on the board
MOTOR_B_BEMF: IC4.22 (AN9/RB9); also elsewhere on the board
MOTOR_B_IN1: IC4.63 (PWM2H/RE3); also elsewhere on the board
MOTOR_B_IN2: IC4.62 (PWM2L/RE2); also elsewhere on the board
MOTOR_C_BEMF: IC4.23 (TMS/AN10/RB10); also elsewhere on the board
MOTOR_C_IN1: IC4.1 (PWM3H/RE5); also elsewhere on the board
MOTOR_C_IN2: IC4.64 (PWM3L/RE4); also elsewhere on the board
MOTOR_D_BEMF: IC4.24 (TDO/AN11/RB11); also elsewhere on the board
MOTOR_D_IN1: IC4.3 (PWM4H/RE7); also elsewhere on the board
MOTOR_D_IN2: IC4.2 (PWM4L/RE6); also elsewhere on the board
unnamed: C10.1, IC4.19 (V+), L1.1
unnamed: C15.1, IC4.56 (V+)
PGC: IC4.17 (PGEC1/AN6/OCFA/RB6); also elsewhere on the board
PGD: IC4.18 (PGED1/AN7/RB7); also elsewhere on the board
RADIO_IRQ: IC4.45 (IC4/INT4/RD11); also elsewhere on the board
RADIO_SLP_TR: IC4.30 (AN15/OCFB/CN12/RB15); also elsewhere on the board
RD_LED: IC4.27 (TCK/AN12/RB12); also elsewhere on the board
SCK1: IC4.35 (!U1RTS!/SCK1/INT0/RF6); also elsewhere on the board
SCK2: IC4.4 (SCK2/CN8/RG6); also elsewhere on the board
SCL1: IC4.37 (SCL1/RG2), R4.1; also elsewhere on the board
SDA1: IC4.36 (SDA1/RG3), R5.1; also elsewhere on the board
SDI1: IC4.34 (U1RX/SDI1/RF2); also elsewhere on the board
SDI2: IC4.5 (SDI2/CN9/RG7); also elsewhere on the board
SDO1: IC4.33 (U1TX/SDO1/RF3); also elsewhere on the board
SDO2: IC4.6 (SDO2/CN10/RG8); also elsewhere on the board
U2RX: IC4.31 (U2RX/SDA2/CN17/RF4); also elsewhere on the board
U2TX: IC4.32 (U2TX/SCL2/CN18/RF5); also elsewhere on the board
YW_LED: IC4.29 (!U2RTS!/AN14/RB14); also elsewhere on the board

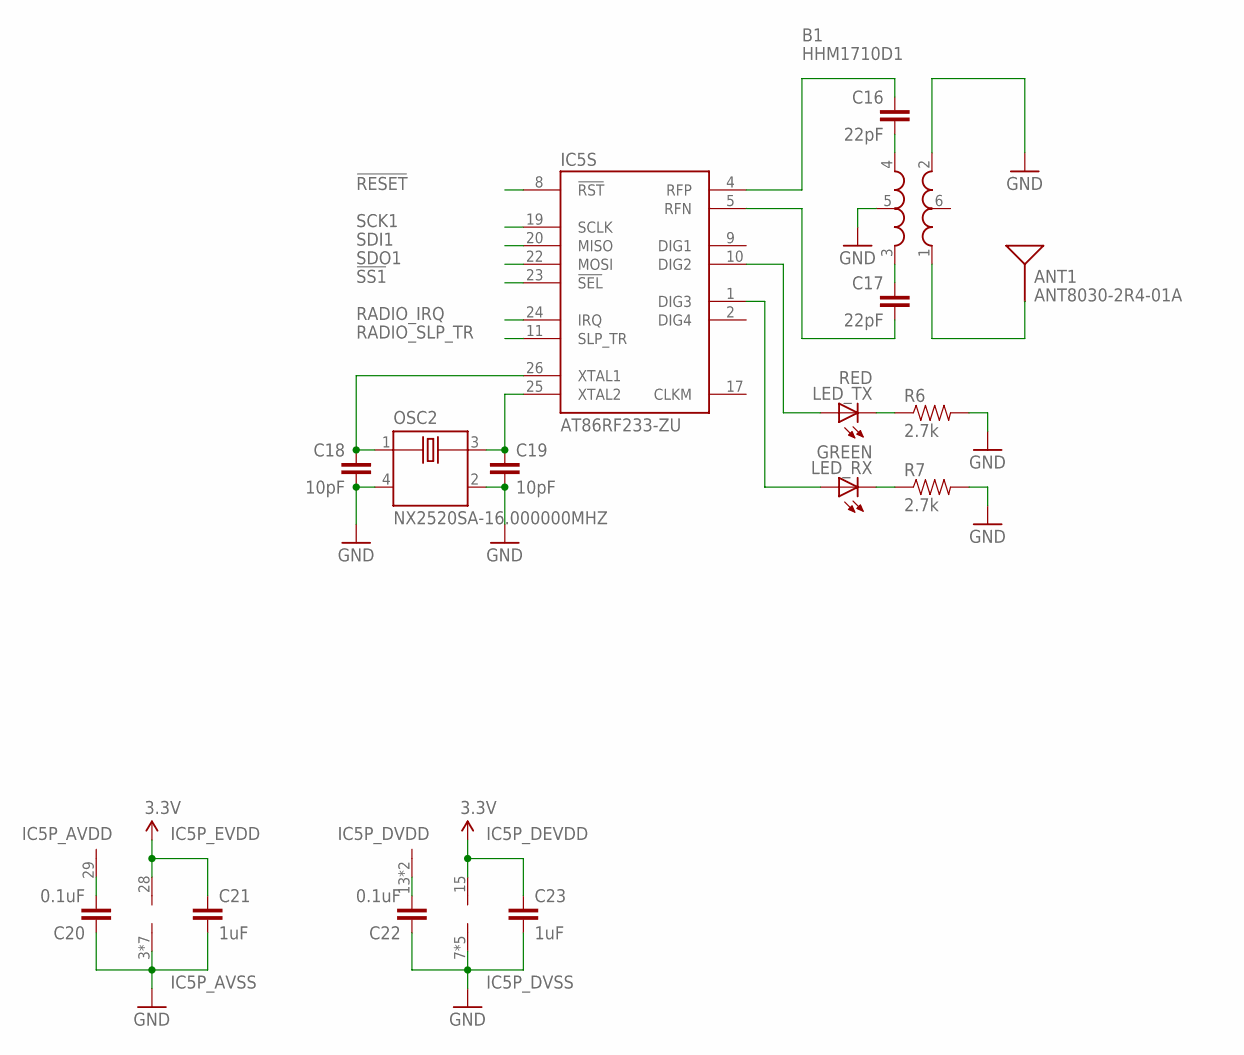
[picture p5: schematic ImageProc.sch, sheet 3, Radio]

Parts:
ANT1: ANT8030-2R4-01A
B1: HHM1710D1; 0603-BALUN
C16, C17: 22pF; 0402-CAP; TOLERANCE 5%; VOLTAGE 50V
C18, C19: 10pF; 0402-CAP; TOLERANCE 10%; VOLTAGE 50V
C20, C22: 0.1uF; 0402-CAP; TOLERANCE 10%; VOLTAGE 16V
C21, C23: 1uF; 0402-CAP; TOLERANCE 10%; VOLTAGE 16V
IC5: AT86RF233-ZU; VQFN-32QN2
LED_RX: GREEN; LED-0603
LED_TX: RED; LED-0603
OSC2: NX2520SA-16.000000MHZ; CRYSTAL-SMD
R6, R7: 2.7k; 0402-RES

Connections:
3.3V: C21.1, C23.1, IC5.15 (V+), IC5.28 (V+); also elsewhere on the board
!RESET: IC5.8 (!RST); also elsewhere on the board
!SS1: IC5.23 (!SEL); also elsewhere on the board
GND: B1.2 (RFGND), B1.5 (GND), C18.2, C19.2, C20.1, C21.2, C22.1, C23.2, IC5.3 (V-), IC5.6 (V-), IC5.7 (V-), IC5.12 (V-), IC5.16 (V-), IC5.18 (V-), IC5.21 (V-), IC5.27 (V-), IC5.30 (V-), IC5.31 (V-), IC5.32 (V-), IC5.PAD (V-), OSC2.2 (GND), OSC2.4 (GND), R6.2, R7.2; also elsewhere on the board
unnamed: C22.2, IC5.13 (V+), IC5.14 (V+)
unnamed: C20.2, IC5.29 (V+)
unnamed: ANT1.A, B1.1 (UNBAL)
unnamed: LED_TX.C, R6.1
unnamed: C16.1, IC5.4 (RFP)
unnamed: C17.2, IC5.5 (RFN)
unnamed: C19.1, IC5.25 (XTAL2), OSC2.3 (OUT/IN)
unnamed: C18.1, IC5.26 (XTAL1), OSC2.1 (IN/OUT)
unnamed: B1.3 (BAL3), C17.1
unnamed: LED_RX.C, R7.1
unnamed: B1.4 (BAL4), C16.2
unnamed: IC5.1 (DIG3), LED_RX.A
unnamed: IC5.10 (DIG2), LED_TX.A
RADIO_IRQ: IC5.24 (IRQ); also elsewhere on the board
RADIO_SLP_TR: IC5.11 (SLP_TR); also elsewhere on the board
SCK1: IC5.19 (SCLK); also elsewhere on the board
SDI1: IC5.20 (MISO); also elsewhere on the board
SDO1: IC5.22 (MOSI); also elsewhere on the board

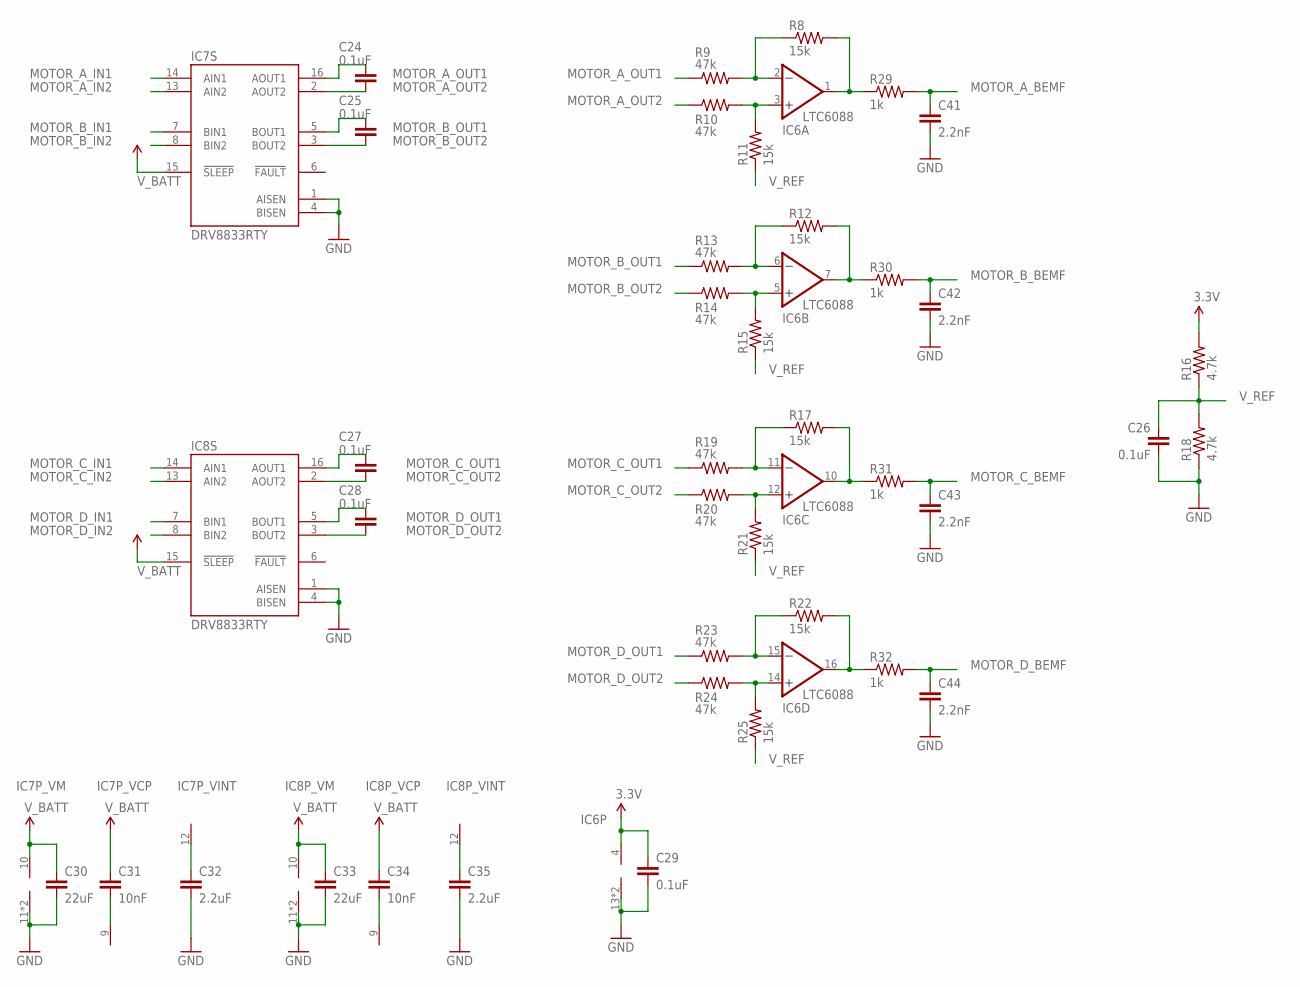
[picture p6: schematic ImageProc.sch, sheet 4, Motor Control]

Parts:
C24, C25, C27, C28: 0.1uF; 0402-CAP; VOLTAGE 10V
C26, C29: 0.1uF; 0402-CAP
C30, C33: 22uF; 0603-CAP
C31, C34: 10nF; 0402-CAP; VOLTAGE 16V
C32, C35: 2.2uF; 0402-CAP; VOLTAGE 6.3V
C41, C42, C43, C44: 2.2nF; 0402-CAP
IC6: LTC6088; DFN-16
IC7, IC8: DRV8833RTY; S-PWQFN-N16
R8, R11, R12, R15, R17, R21, R22, R25: 15k; 0402-RES; TOLERANCE 1%
R9, R10, R13, R14, R19, R20, R23, R24: 47k; 0402-RES; TOLERANCE 1%
R16, R18: 4.7k; 0402-RES; TOLERANCE 1%
R29, R30, R31, R32: 1k; 0402-RES

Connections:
3.3V: C29.1, IC6.4 (V+), R16.2; also elsewhere on the board
GND: C26.2, C29.2, C30.2, C32.2, C33.2, C35.2, C41.2, C42.2, C43.2, C44.2, IC6.13 (V-), IC6.PAD (V-), IC7.1 (AISEN), IC7.4 (BISEN), IC7.11 (V-), IC7.PPAD (V-), IC8.1 (AISEN), IC8.4 (BISEN), IC8.11 (V-), IC8.PPAD (V-), R18.1; also elsewhere on the board
MOTOR_A_BEMF: C41.1, R29.2; also elsewhere on the board
MOTOR_A_IN1: IC7.14 (AIN1); also elsewhere on the board
MOTOR_A_IN2: IC7.13 (AIN2); also elsewhere on the board
MOTOR_A_OUT1: C24.1, IC7.16 (AOUT1), R9.1; also elsewhere on the board
MOTOR_A_OUT2: C24.2, IC7.2 (AOUT2), R10.1; also elsewhere on the board
MOTOR_B_BEMF: C42.1, R30.2; also elsewhere on the board
MOTOR_B_IN1: IC7.7 (BIN1); also elsewhere on the board
MOTOR_B_IN2: IC7.8 (BIN2); also elsewhere on the board
MOTOR_B_OUT1: C25.1, IC7.5 (BOUT1), R13.1; also elsewhere on the board
MOTOR_B_OUT2: C25.2, IC7.3 (BOUT2), R14.1; also elsewhere on the board
MOTOR_C_BEMF: C43.1, R31.2; also elsewhere on the board
MOTOR_C_IN1: IC8.14 (AIN1); also elsewhere on the board
MOTOR_C_IN2: IC8.13 (AIN2); also elsewhere on the board
MOTOR_C_OUT1: C27.1, IC8.16 (AOUT1), R19.1; also elsewhere on the board
MOTOR_C_OUT2: C27.2, IC8.2 (AOUT2), R20.1; also elsewhere on the board
MOTOR_D_BEMF: C44.1, R32.2; also elsewhere on the board
MOTOR_D_IN1: IC8.7 (BIN1); also elsewhere on the board
MOTOR_D_IN2: IC8.8 (BIN2); also elsewhere on the board
MOTOR_D_OUT1: C28.1, IC8.5 (BOUT1), R23.1; also elsewhere on the board
MOTOR_D_OUT2: C28.2, IC8.3 (BOUT2), R24.1; also elsewhere on the board
unnamed: C31.2, IC7.9 (V+)
unnamed: C32.1, IC7.12 (V-)
unnamed: C34.2, IC8.9 (V+)
unnamed: C35.1, IC8.12 (V-)
unnamed: IC6.6 (-IN), R12.1, R13.2
unnamed: IC6.5 (+IN), R14.2, R15.2
unnamed: IC6.11 (-IN), R17.1, R19.2
unnamed: IC6.12 (+IN), R20.2, R21.2
unnamed: IC6.15 (-IN), R22.1, R23.2
unnamed: IC6.14 (+IN), R24.2, R25.2
unnamed: IC6.2 (-IN), R8.1, R9.2
unnamed: IC6.3 (+IN), R10.2, R11.2
unnamed: IC6.16 (OUT), R22.2, R32.1
unnamed: IC6.10 (OUT), R17.2, R31.1
unnamed: IC6.1 (OUT), R8.2, R29.1
unnamed: IC6.7 (OUT), R12.2, R30.1
V_BATT: C30.1, C31.1, C33.1, C34.1, IC7.10 (V+), IC7.15 (!SLEEP), IC8.10 (V+), IC8.15 (!SLEEP); also elsewhere on the board
V_REF: C26.1, R11.1, R15.1, R16.1, R18.2, R21.1, R25.1

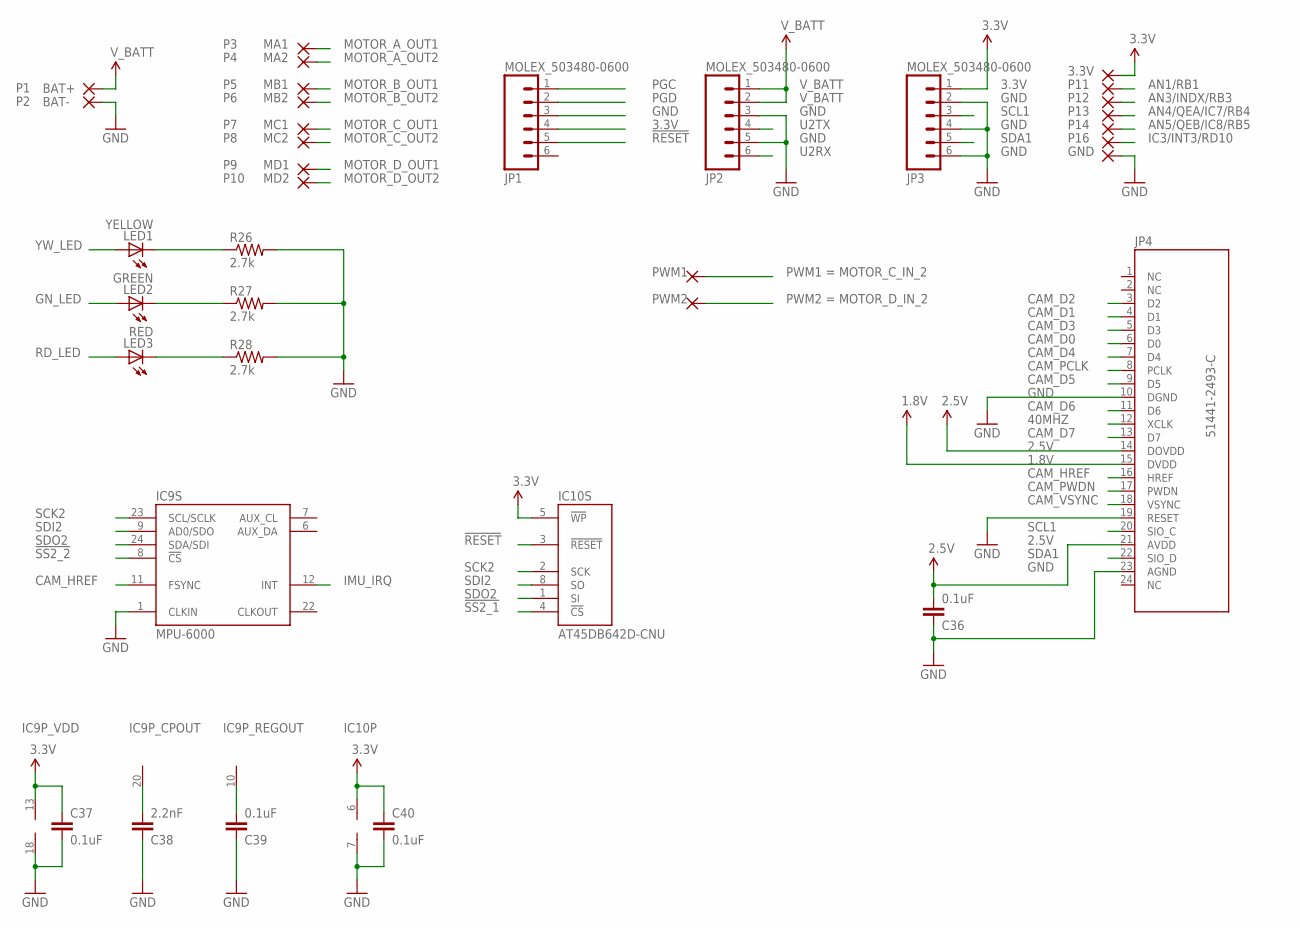
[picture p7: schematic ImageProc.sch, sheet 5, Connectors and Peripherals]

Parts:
3.3V: EXT5; SMD1,27-2,54
C36, C40: 0.1uF; 0402-CAP
C37: 0.1uF; 0402-CAP; TOLERANCE 10%; VOLTAGE 4V
C38: 2.2nF; 0402-CAP; TOLERANCE 10%; VOLTAGE 50V
C39: 0.1uF; 0402-CAP; TOLERANCE 10%; VOLTAGE 2V
GND: EXT5; SMD1,27-2,54
IC9: MPU-6000; QFN-24
IC10: AT45DB642D-CNU; CASON-8
JP1, JP2, JP3: MOLEX_503480-0600
JP4: 51441-2493-C; MOLEX_52740-2490
LED1: YELLOW; LED-0603
LED2: GREEN; LED-0603
LED3: RED; LED-0603
P1: BAT+; SMD1,27-2,54
P2: BAT-; SMD1,27-2,54
P3: MA1; SMD1,27-2,54
P4: MA2; SMD1,27-2,54
P5: MB1; SMD1,27-2,54
P6: MB2; SMD1,27-2,54
P7: MC1; SMD1,27-2,54
P8: MC2; SMD1,27-2,54
P9: MD1; SMD1,27-2,54
P10: MD2; SMD1,27-2,54
P11: EXT1; SMD1,27-2,54
P12: EXT2; SMD1,27-2,54
P13: EXT3; SMD1,27-2,54
P14: EXT4; SMD1,27-2,54
P16: EXT5; SMD1,27-2,54
PWM1, PWM2: EXT5; SMD1,27-2,54
R26, R27, R28: 2.7k; 0402-RES

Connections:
1.8V: JP4.15 (DVDD); also elsewhere on the board
2.5V: C36.2, JP4.14 (DOVDD), JP4.21 (AVDD); also elsewhere on the board
3.3V: 3.3V.1, C37.1, C40.1, IC9.13 (V+), IC10.5 (!WP), IC10.6 (V+), JP1.4, JP3.1; also elsewhere on the board
40MHZ: JP4.12 (XCLK); also elsewhere on the board
!RESET: IC10.3 (!RESET), JP1.5; also elsewhere on the board
!SS2_1: IC10.4 (!CS); also elsewhere on the board
!SS2_2: IC9.8 (!CS); also elsewhere on the board
AN1/RB1: P11.1; also elsewhere on the board
AN3/INDX/RB3: P12.1; also elsewhere on the board
AN4/QEA/IC7/RB4: P13.1; also elsewhere on the board
AN5/QEB/IC8/RB5: P14.1; also elsewhere on the board
CAM_D0: JP4.6 (D0); also elsewhere on the board
CAM_D1: JP4.4 (D1); also elsewhere on the board
CAM_D2: JP4.3 (D2); also elsewhere on the board
CAM_D3: JP4.5 (D3); also elsewhere on the board
CAM_D4: JP4.7 (D4); also elsewhere on the board
CAM_D5: JP4.9 (D5); also elsewhere on the board
CAM_D6: JP4.11 (D6); also elsewhere on the board
CAM_D7: JP4.13 (D7); also elsewhere on the board
CAM_HREF: IC9.11 (FSYNC), JP4.16 (HREF); also elsewhere on the board
CAM_PCLK: JP4.8 (PCLK); also elsewhere on the board
CAM_PWDN: JP4.17 (PWDN); also elsewhere on the board
CAM_VSYNC: JP4.18 (VSYNC); also elsewhere on the board
GND: C36.1, C37.2, C38.1, C39.1, C40.2, GND.1, IC9.1 (CLKIN), IC9.18 (V-), IC10.7 (V-), JP1.3, JP2.3, JP2.5, JP3.2, JP3.4, JP3.6, JP4.10 (DGND), JP4.19 (RESET), JP4.23 (AGND), P2.1, R26.2, R27.2, R28.2; also elsewhere on the board
GN_LED: LED2.A; also elsewhere on the board
IC3/INT3/RD10: P16.1; also elsewhere on the board
IMU_IRQ: IC9.12 (INT); also elsewhere on the board
MOTOR_A_OUT1: P3.1; also elsewhere on the board
MOTOR_A_OUT2: P4.1; also elsewhere on the board
MOTOR_B_OUT1: P5.1; also elsewhere on the board
MOTOR_B_OUT2: P6.1; also elsewhere on the board
MOTOR_C_IN2: PWM1.1; also elsewhere on the board
MOTOR_C_OUT1: P7.1; also elsewhere on the board
MOTOR_C_OUT2: P8.1; also elsewhere on the board
MOTOR_D_IN2: PWM2.1; also elsewhere on the board
MOTOR_D_OUT1: P9.1; also elsewhere on the board
MOTOR_D_OUT2: P10.1; also elsewhere on the board
unnamed: LED1.C, R26.1
unnamed: LED2.C, R27.1
unnamed: LED3.C, R28.1
unnamed: C38.2, IC9.20 (V-)
unnamed: C39.2, IC9.10 (V-)
PGC: JP1.1; also elsewhere on the board
PGD: JP1.2; also elsewhere on the board
RD_LED: LED3.A; also elsewhere on the board
SCK2: IC9.23 (SCL/SCLK), IC10.2 (SCK); also elsewhere on the board
SCL1: JP3.3, JP4.20 (SIO_C); also elsewhere on the board
SDA1: JP3.5, JP4.22 (SIO_D); also elsewhere on the board
SDI2: IC9.9 (AD0/SDO), IC10.8 (SO); also elsewhere on the board
SDO2: IC9.24 (SDA/SDI), IC10.1 (SI); also elsewhere on the board
U2RX: JP2.6; also elsewhere on the board
U2TX: JP2.4; also elsewhere on the board
V_BATT: JP2.1, JP2.2, P1.1; also elsewhere on the board
YW_LED: LED1.A; also elsewhere on the board

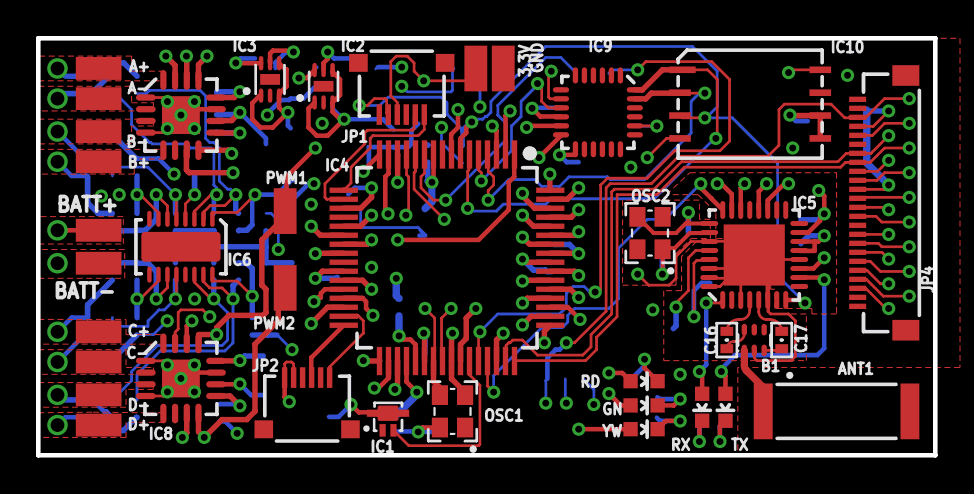
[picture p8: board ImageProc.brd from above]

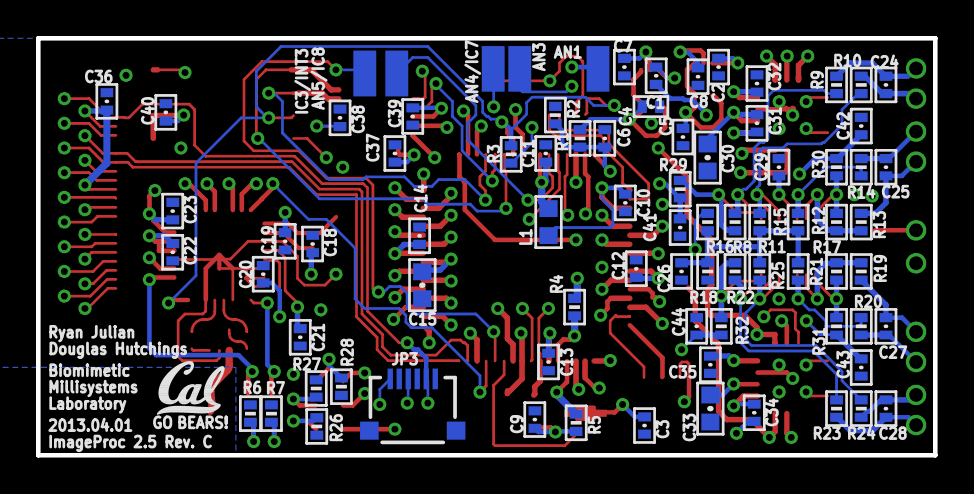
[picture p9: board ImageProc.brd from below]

Board: 4 copper layers, 49.8 x 23.2 mm, 119 parts (81 on the bottom side), 105 nets.

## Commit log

2012-05-09 Added camera breakout board.
    [CameraBreakout_PCB.SLDDRW]
2012-05-09 Added ImageProc1 and MotorDriver1 pcbs, superseding the CameraBreakout board.
    [CameraBreakout_PCB.SLDDRW]
2012-05-09 Added ImageProc2, superseding ImageProc1+MotorDriver1.
    [ImageProc2_ver_22.brd, ImageProc2_ver_22.sch]
2012-05-09 Added ImageProc2.24.
    [ImageProc2_ver_22.brd, ImageProc2_ver_22.sch, ImageProc2_ver_24c.brd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]
2012-05-10 Getting rid of ImageProc folder, for now.
    [ImageProc2_ver_24c.brd, ImageProc2_ver_24c.sch]
2012-06-16 *Added biomimetic.lbr (only has schematic frame for now) *Added initial schematics and old layout *Added 66each design rules *Began separating schematic elements info different sheets
    [ImageProc2_ver_24c.brd, ImageProc2_ver_24c.sch, ImageProc2_ver_24d.brd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]
2012-06-29 Stopped commiting for a week. Oops.
    [ImageProc_2.5.brd]
2012-06-29 Stopped committing for a week. Oops.
    [ImageProc_2.5.sch]
2012-06-30 Before work 6/30
    [ImageProc_2.5.brd, ImageProc_2.5.sch]
2012-06-30 Work 6/30
    [ImageProc_2.5.brd, ImageProc_2.5.sch]
2012-06-30 Commit before replace LTC6088 with LT1991
    [ImageProc_2.5.brd, ImageProc_2.5.sch]
2012-07-02 Partial motor driver route. Motor drive vias moved to edge (could be used for strain relief).
    [ImageProc_2.5.brd]
2012-07-02 Motor section mostly complete, except motor controller power and PIC analog pins. Camera connector escape complete. Edited PIC keepout to be tighter.
    [ImageProc_2.5.brd, ImageProc_2.5.sch]
2012-07-03 Partial antenna and RF route. Adjusted ground planes to avoid antenna and moved antenna to lower-right corner, moved OVCAM connector up to make room.
    [ImageProc_2.5.brd]
2012-07-03 RF top layout complete
    [ImageProc_2.5.brd, ImageProc_2.5.sch]
2012-07-03 Added tPlace outlines to 0603s and 0402s
    [ImageProc_2.5.brd, ImageProc_2.5.sch]
2012-07-04 Partial IMU/flash route. PIC, IMU, and flash locations locked. Passives for IMU/flash.
    [ImageProc_2.5.brd, ImageProc_2.5.sch]
2012-07-05 Motor section mostly complete. Board expanded. PIC passives mostly complete.
    [ImageProc_2.5.brd, ImageProc_2.5.sch]
2012-07-07 PIC and radio vias added. Partial camera route.
    [ImageProc_2.5.brd, ImageProc_2.5.sch]
2012-07-07 More camera connector routed. Vias on right side of PIC re-spaced.
    [ImageProc_2.5.brd]
2012-07-09 Added anti-aliasing filter values (not sure how I missed those). Renamed external pins.
    [ImageProc_2.5.brd, ImageProc_2.5.sch]
2012-07-10 first few routes on ground
    [ImageProc_2.5.brd]
2012-07-10 first few traces on ground
2012-07-13 Routed Several more connections.
    Placed LEDS and added vias for it.
    Placed Connector On Bottom.
    Deleted some badly planned connections from last time.
    [ImageProc_2.5.brd]
2012-07-13 More routs seperated jp3 and the 2 7-pin components
    [ImageProc_2.5.brd]
2012-07-13 Moved an LED
    Added wires to ground plane
    [ImageProc_2.5.brd]
2012-07-13 Removed incorrectly wired bypass caps on the regulators
    [ImageProc_2.5.brd]
2012-07-13 placed and wired the bypass caps for the 2 regulators.
    Placed and wired the voltage divider on sheet 1 of the schematic
    [ImageProc_2.5.brd]
2012-07-15 34 air wires left.
    Espescially improved area around mpu 6000
    Running into problems with areas of the 3.3 and GND planes being cutoff due to many traces in their planes.
    Next step: shift wires in the ground plane near the mpu6000 to allow for vias in the groundplane to carry the pad outputs.
    [ImageProc_2.5.brd]
2012-07-15 commmit of the last commit????
    [ImageProc_2.5.brd]
2012-07-16 ran DRC, fixed DRC issues for top and ground.
    [ImageProc_2.5.brd]
2012-07-16 Fixed rest of the initial DRC errors.
    Down to 24 air wires.
    Having to be creative for the pads.
    [ImageProc_2.5.brd]
2012-07-17 17 airwires left.
    did most of the wiring of the pads && the relocating of various ground and power layer wires to compensate.
    [ImageProc_2.5.brd]
2012-07-17 3 airwires left….
    begun fixing the airwires in the motor controller section
    [ImageProc_2.5.brd]
2012-07-17 Zero Airwires, fixed the restrict DRC errors.
    Now proceeding to (hopefully final) DRC
    [ImageProc_2.5.brd]
2012-07-18 0 Airwires, 0 non-ignored DRC Errors.
    [ImageProc_2.5.brd]
2012-07-18 Adding dual FET driver variant of ImageProc2 board.
    [ImageProc2_ver_24d.brd, ImageProc2_ver_24d.sch]
2012-07-18 Adding dual FET driver + new FPC ZIF programming connector variant of ImageProc2 board.
    [ImageProc2_ver_24e.brd, ImageProc2_ver_24e.sch]
2012-08-15 ImageProc 2.5 Rev. A
    Final silk screen and manufacturing modifications. Submitted for
    prototype manufacturing on 7/26/2012.
    ImageProc 2.5 updates the ImageProc with several new features and updated
    silicon, while focusing on on enhanced manufacturability and ease of
    modification. Software revisions to the octoroach and imageproc-lib codebases
    are forthcoming.
    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
    [ImageProc_2.5.brd, ImageProc_2.5.sch]
2012-08-15 Added sheet name headings
    [ImageProc.sch]
2012-08-23 Initial commit of the erratta.
    hardware verified: Power, dpsic, radio, both h-bridges, LED.
2012-08-27 Resolved the three wiring issues (non-connect on the v_batt plane, non-connect for a logic ground, and programming connector backwards).
    Added the biomimetics dru's
    [ImageProc.brd, ImageProc.sch]
2012-08-27 Nudged the outside vias and pads to get sufficient edge clearance.
    [ImageProc.brd]
2012-08-27 Changed the revision letter in the silkscreen to "B".
    [ImageProc.brd]
2012-09-03 Fixed many of 2.5 A's erratta, to form 2.5B.
    Fixed the top motor controller's missing GND pin.
    Fixed the Radio Chip's pins that were combined.
    Fixed C37/C40 mislabeling.
    [ImageProc.brd]
2012-09-03 Updated this schematic to revision 2.5B.
    Changed the revision # in the bottom right corner.
    Also modified to fix the motor controller Ground pin issue.
    [ImageProc.sch]
2012-09-14 Added Pads for PWM 1 and 2 to MOTOR_C_IN_2 and MOTOR_D_IN_2 on the top.
    Added this both to the schematic and routed it on the board.
    [ImageProc.brd, ImageProc.sch]
2012-09-18 Update PCB date, correct bridge on AT86RF233
    [ImageProc.brd]
2012-10-23 Fix transposed SDA1/SCL1 on dsPIC
    [ImageProc.brd, ImageProc.sch]
2012-12-14 Pinouts spread sheet updated for IP 2.5c
    [imageproc25c-pinouts.xls]
2012-12-15 changed comment in .xls to current date
    [imageproc25c-pinouts.xls]
2013-02-01 Create Pinout.md
    Table of dsPIC pin/port assignments, as well at net names and plain
    english descriptions.
2013-02-01 Remove pinout Excel spreadsheet
    Superceded by Pinout.md
    [imageproc25c-pinouts.xls]
2013-02-01 Update datecode for new order
    [ImageProc.brd]
2013-05-31 Add BOM and CPL
    [BOM.csv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]
2014-04-23 Changed layer state for schematic.
    [ImageProc.brd]

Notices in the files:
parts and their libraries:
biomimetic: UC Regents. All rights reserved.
